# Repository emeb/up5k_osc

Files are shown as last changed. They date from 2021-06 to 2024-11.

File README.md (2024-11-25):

# up5k_osc
An FPGA-based digital oscillator for Eurorack

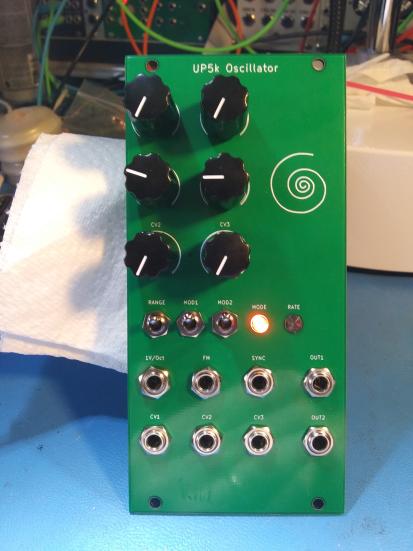
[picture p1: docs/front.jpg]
Front View

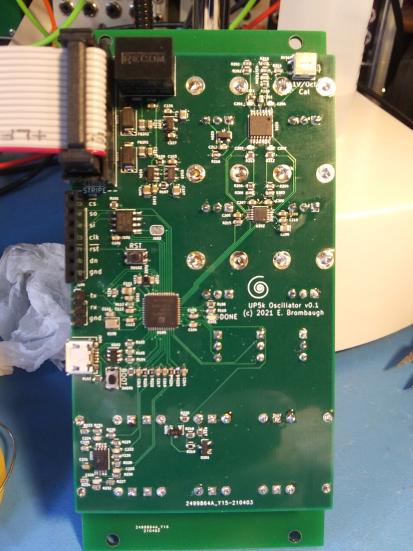
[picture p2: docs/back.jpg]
Back View


## What is it?
up5k_osc is a Eurorack-format digital oscillator demonstrating digital
audio synthesis with a low-cost FPGA. It supports several basic waveforms
commonly found in analog synthesizers, but generated digitally at very high
sample rates to avoid many of the problems with aliasing that occur when
these waveforms are synthesized at lower sample rates.

## Features

* 12HP wide 3U standard Eurorack module
* +/-12V supply on Doepfer-standard 16-pin shrouded, keyed header (30ma max)
* Trimmed 1V/Oct pitch control input with coarse and fine adjustment pots
* Attenuated Exponential FM input
* 3 additional uncommited +/-5V CV inputs with associated setting pots
* Sync input
* Two +/-5V range audio outputs
* Three 3 position toggles for range and mode control
* RGB LED indicator
* Additional single LED indicator
* USB-based firmware updates

## Design details
* Lattice iCE40 Ultra Plus 5k FPGA
* 4MB SPI Flash memory for configuration data, firmware and tables.
* 4-channel 12-bit SPI ADC with 500kSPS max sample rate
* Direct-access SPI Programming header
* 3-pin diagnostic header (2 data + ground)
* Reset and Bootloader pushbuttons
* Done Program LED
* Buck SMPS regulator for low current draw from +12V supply
* Differential PDM DACs for high-resolution, high sample rate and low THD audio

## Resources
* [Schematic](docs/up5k_osc_schematic.pdf)
* [BOM](docs/up5k_osc_bom.ods)

## Motivation
One of the most thorny issues encountered when attempting to synthesize simple
analog waveforms in the digital domain is that of aliasing which occurs due
to sharp transitions coupled with low sample rates. Seemingly "obvious" methods
of generating simple waveforms like sawtooths and square or pulse waves fail
miserably when the sharp edges of these waveforms jitter around due to the low
timing resolution of practical DSP sample rates. Mountains of research have been
devoted to DSP approaches to minimizing this edge jitter using techniques such
as BLIT, BLEP, MinBLEP, PolyBLEP, DPW, etc. These work, but end up becoming
compromises between the complexity of the approach (and the consequent CPU load
they impose) and the degree of alias rejection that they provide.

The brute-force approach is to synthesize these analog waveforms at sufficiently
high sample rates that the timing jitter becomes imperceptible. This is the
method that up5k_osc uses - an audio-rate oscillator is synthesized at sample
rates in excess of 10MHz which knocks the aliases of even the buzziest narrow
pulse wave down below 80dBfs. Differential Pulse Density Modulation is used to
do the digital-to-analog conversion in an inexpensive yet highly linear fashion.

## Theory of Operation
The up5k_osc system comprises a power supply, ADC, Flash Memory, FPGA and analog
I/O processing. 

### Power Supply
Eurorack systems typically provide +/-12V rails at a minimum, and as DSP becomes
a more common feature in typical racks, the +12V rails are disproportionally
loaded down by the use of simple LDO linear regulators to supply the high currents
needed by most modern digital components. up5k_osc uses a SMPS regulator module
to efficiently provide an internal 5V supply from which 3.3V analog and digital
supplys can be derived with less heat and waste.

### Analog Input Processing
A 4-channel 12-bit 500kSPS SPI ADC is used to digitize control voltage inputs
to the up5k_osc. One channel is dedicated to handling the typical 1V/Oct pitch
control and includes trimming to calibrate the 1V/Oct slope, as well as coarse
and fine user offsets as well as summing an attenuated FM input. This provides
roughly 2.7cents/lsb pitch resolution over a 10V range which covers most of
the musical range to an accuracy better than the commonly accepted human
perception.

The other three ADC channels are uncommitted CV inputs with offset controls and
a 10Vpp range. Running that the maximum rated conversion speed, the ADC can
provide 125kSPS per channel which is sufficiently high to provide good temporal
resolution.

### FPGA and SPI Flash
The Lattice iCE40 Ultra Plus 5k FPGA provides a modest gate count, a number of
useful hard IP cores, including SPI, I2C, Multiply-Accumulate and large RAM.
These resources are sufficient for reasonably complex DSP, soft processor cores
and I/O tasks. In the up5k_osc, the FPGA is loaded from the SPI Flash at power
up and immediately begins execution of a basic processing pipeline which begins
with driving a continuous stream of conversions from the ADC, formatting the
results for control of a fast internal NCO, waveshaping and then finally
generating the PDM output signals.

FPGA bitstreams, along with soft processor firmware and synthesis tables are
stored in the SPI flash. During development it's often simplest to directly load
the FPGA over the SPI configuration bus via a programming dongle and header on
the board, bypassing the SPI flash. In end-use situations however it's desirable
to have a simpler approach, and for that purpose a USB interface is provided
which uses the NO2 bootloader and the standardized DFU protocol to load data
into the SPI flash without extra hardware.

[NO2 Bootloader](https://github.com/no2fpga/no2bootloader)

The up5k_osc FPGA pinout for USB, SPI Flash and boot select button + LED has
been designed to follow that of the icebreaker bitsy, so building the
bootloader with that configuration will generate a usable bitstream.

### Switches and LEDs
User control options are provided in the form of three 3-position SPDT toggles
(on-off-on) which can be used to set pitch range, waveform types, etc. A few
LEDs are also provided to indicate operating conditions.

### Analog Outputs
Two PDM DACs are available with fully differential inputs from the FPGA to
improve linearity despite mismatches in rise & fall timing. A two-stage
lowpass reconstruction filter rolls off at about 30kHz, allowing harmonic
content well above normal human hearing range. SNR has been observed as better
that 90dBfs, THD for 1kHz sine is better than 80dBfs and with 16MSPS sample
rates the aliasing on naive sawtooth waveforms are lower than 80dBfs beyond
10kHz. Output levels of 10Vpp are compatible with common Eurorack standards.

## Gateware
Demonstration gateware for the up5k_osc is provided which handles all the basic
functions of an oscillator. Three pitch ranges are provided which cover rates
from 13min/cycle to 10kHz. Two output waveforms can be selected from among
sine/saw/pulse, with pulsewidth controlled by one of the CV inputs.

As delivered the demo gateware does not use a soft processor core. A serial
diagnostic output is generated by simple state machine logic to provide
observation of the ADC conversion results (formatted as 115k 8N1 serial). An
alternate build is possible via macro definitions in the source code that
enables a RISC-V core that can do more complex diagnostics, or even control
the oscillator with some imagination and more coding.

## Future Work
Going beyond this is certainly possible - wavetable morphing has been tested and
other synthesis techniques such as multi-operator FM are possible. The USB
interface could be employed to turn the module into an Audio class peripheral
that handles MIDI or PCM audio.

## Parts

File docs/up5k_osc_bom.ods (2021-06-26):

Reference | Quantity | Value | Footprint | Distributor
C102 C103 C215 C216 C218 C226 | 6 | 1uf | Capacitors_SMD:C_0603 | stock
C101 C104 C105 C108 C109 C110 C112 C113 C114 C210 C211 C212 C220 C221 | 14 | 0.1uf | Capacitors_SMD:C_0603 | stock
C106 C107 C111 C208 C228 | 5 | 10uf | Capacitors_SMD:C_0805 | stock
C201 C202 C203 C204 | 4 | 330pf | Capacitors_SMD:C_0603 | stock
C213 C214 C217 C219 | 4 | 4.7nf | Capacitors_SMD:C_0603 | Digi-Key
C222 C223 C224 C225 | 4 | 75pf | Capacitors_SMD:C_0603 | Digi-Key
C205 C206 C207 C209 C227 | 5 | 0.01uf | Capacitors_SMD:C_0603 | stock
D101 D104 | 2 | LED | LEDs:LED_0603 | stock
D102 | 1 | D | Diodes_SMD:D_0603 | stock
D103 | 1 | ASMB-KTF0-0A306‎ | footprints:ASMB-KTF0-0A306‎ | stock
D201 | 1 | BAT54S | Package_TO_SOT_SMD:SOT-23 | stock
D205 D206 | 2 | D | Diodes_SMD:D_SMA | stock
FB201 FB202 | 2 | 220 | Resistors_SMD:R_0805 | stock
J101 | 1 | USB_OTG | footprints:USB_Micro-B_10103594-0001LF_actual_outline | stock
J102 | 1 | NC Jumper | Jumper:SolderJumper-2_P1.3mm_Bridged_RoundedPad1.0x1.5mm | `---
J103 | 1 | Conn_01x07 | Pin_Headers:Pin_Header_Straight_1x07_Pitch2.54mm | stock
J104 | 1 | Conn_01x03 | Pin_Headers:Pin_Header_Straight_1x03_Pitch2.54mm | stock
J204 | 1 | Conn_02x08_Odd_Even | footprints:5103308-3 | stock
J201 J202 J203 J205 J206 J207 J208 J209 | 8 | AudioJack2_SwitchT | footprints:Jack_3.5mm_QingPu_WQP-PJ398SM_Vertical_CircularHoles | Thonk / stock
Q201 | 1 | MMBT3904 | TO_SOT_Packages_SMD:SOT-23 | stock
R102 | 1 | 1M | Resistors_SMD:R_0603 | Digi-Key
R103 | 1 | 1.5k | Resistors_SMD:R_0603 | stock
R104 R105 | 2 | 22 | Resistors_SMD:R_0603 | stock
R107 R109 R201 R203 R205 R207 R208 | 7 | 100k | Resistors_SMD:R_0603 | stock
R101 R106 R108 R217 R218 R220 | 6 | 10k | Resistors_SMD:R_0603 | stock
R110 | 1 | 2.2k | Resistors_SMD:R_0603 | stock
R111 R112 R215 R233 R234 | 5 | 100 | Resistors_SMD:R_0603 | stock
R202 R204 R206 R209 | 4 | 49.9k | Resistors_SMD:R_0603 | stock
R210 | 1 | 1.2M | Resistors_SMD:R_0603 | Digi-Key
R211 R212 R213 | 3 | 33.2k | Resistors_SMD:R_0603 | stock
R214 | 1 | 32.4k | Resistors_SMD:R_0603 | Digi-Key
R216 | 1 | 2.5k | Resistors_SMD:R_0603 | Digi-Key
R219 | 1 | 60k | Resistors_SMD:R_0603 | stock
R221 R222 R223 R224 | 4 | 1k | Resistors_SMD:R_0603 | stock
R225 R226 R227 R228 | 4 | 47k | Resistors_SMD:R_0603 | stock
R229 R230 R231 R232 | 4 | 71.5k | Resistors_SMD:R_0603 | stock
RV201 RV202 RV203 RV204 RV205 RV206 | 6 | 10k | footprints:Potentiometer_TT_P0915N | stock
RV207 | 1 | 1k | footprints:23BR500LFTR | Digi-Key
SW101 SW102 | 2 | SW_Push | Buttons_Switches_SMD:SW_SPST_KMR2 | stock
SW103 SW104 SW105 | 3 | SW_SPDT | footprints:SPDT_Submini | stock
U101 | 1 | W25Q32JVSS | Housings_SOIC:SOIC-8_3.9x4.9mm_Pitch1.27mm | stock
U102 | 1 | NUP4202 | TO_SOT_Packages_SMD:SOT-23-6 | stock
U103 | 1 | MCP1824x-OT | TO_SOT_Packages_SMD:SOT-23-5 | stock
U104 | 1 | MCP1802x-xx02xOT | TO_SOT_Packages_SMD:SOT-23-5 | stock
U105 | 1 | ice5lp4k_sg48 | footprints:QFN-48-1EP_7x7mm_Pitch0.5mm_DIY_PADS | stock
U106 | 1 | 12MHz | Oscillators:Oscillator_SMD_SeikoEpson_SG210-4pin_2.5x2.0mm | stock
U201 | 1 | MCP6004 | Housings_SSOP:TSSOP-14_4.4x5mm_Pitch0.65mm | stock
U202 | 1 | ADC124S051 | Housings_SSOP:MSOP-10_3x3mm_Pitch0.5mm | stock
U203 | 1 | TL072PW | Housings_SSOP:TSSOP-8_4.4x3mm_Pitch0.65mm | stock
U204 | 1 | LM4040DBZ-5 | Package_TO_SOT_SMD:SOT-23 | stock
U205 | 1 | LP2985-3.3 | Package_TO_SOT_SMD:SOT-23-5 | stock
U210 | 1 | R-78E5.0-0.5 | Converter_DCDC:Converter_DCDC_RECOM_R-78E-0.5_THT | Digi-Key
light pipe | 2 | light pipe | na | Digi-Key

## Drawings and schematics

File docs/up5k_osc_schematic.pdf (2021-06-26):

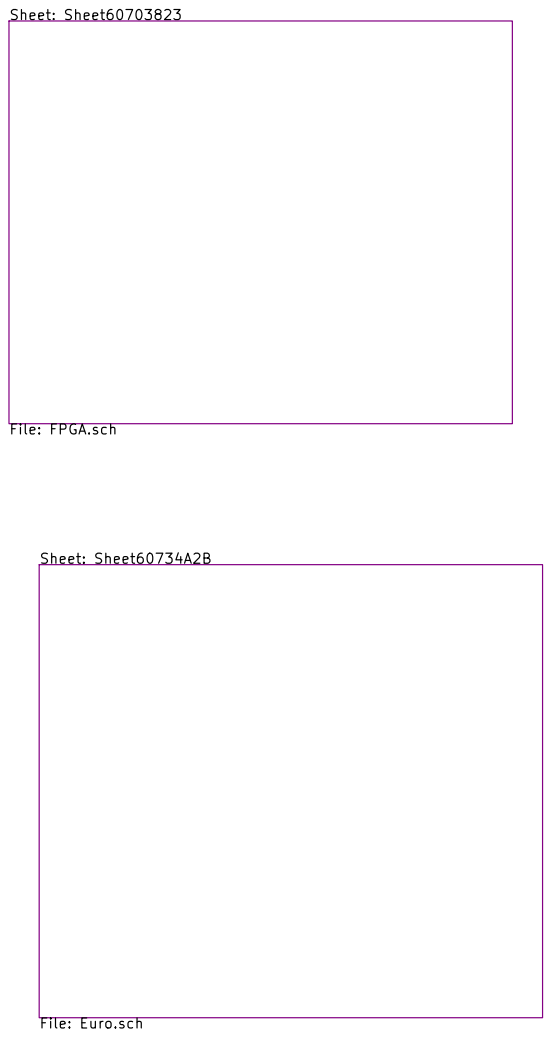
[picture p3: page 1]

Sheet: Sheet60703823 File: FPGA.sch Sheet: Sheet60734A2B

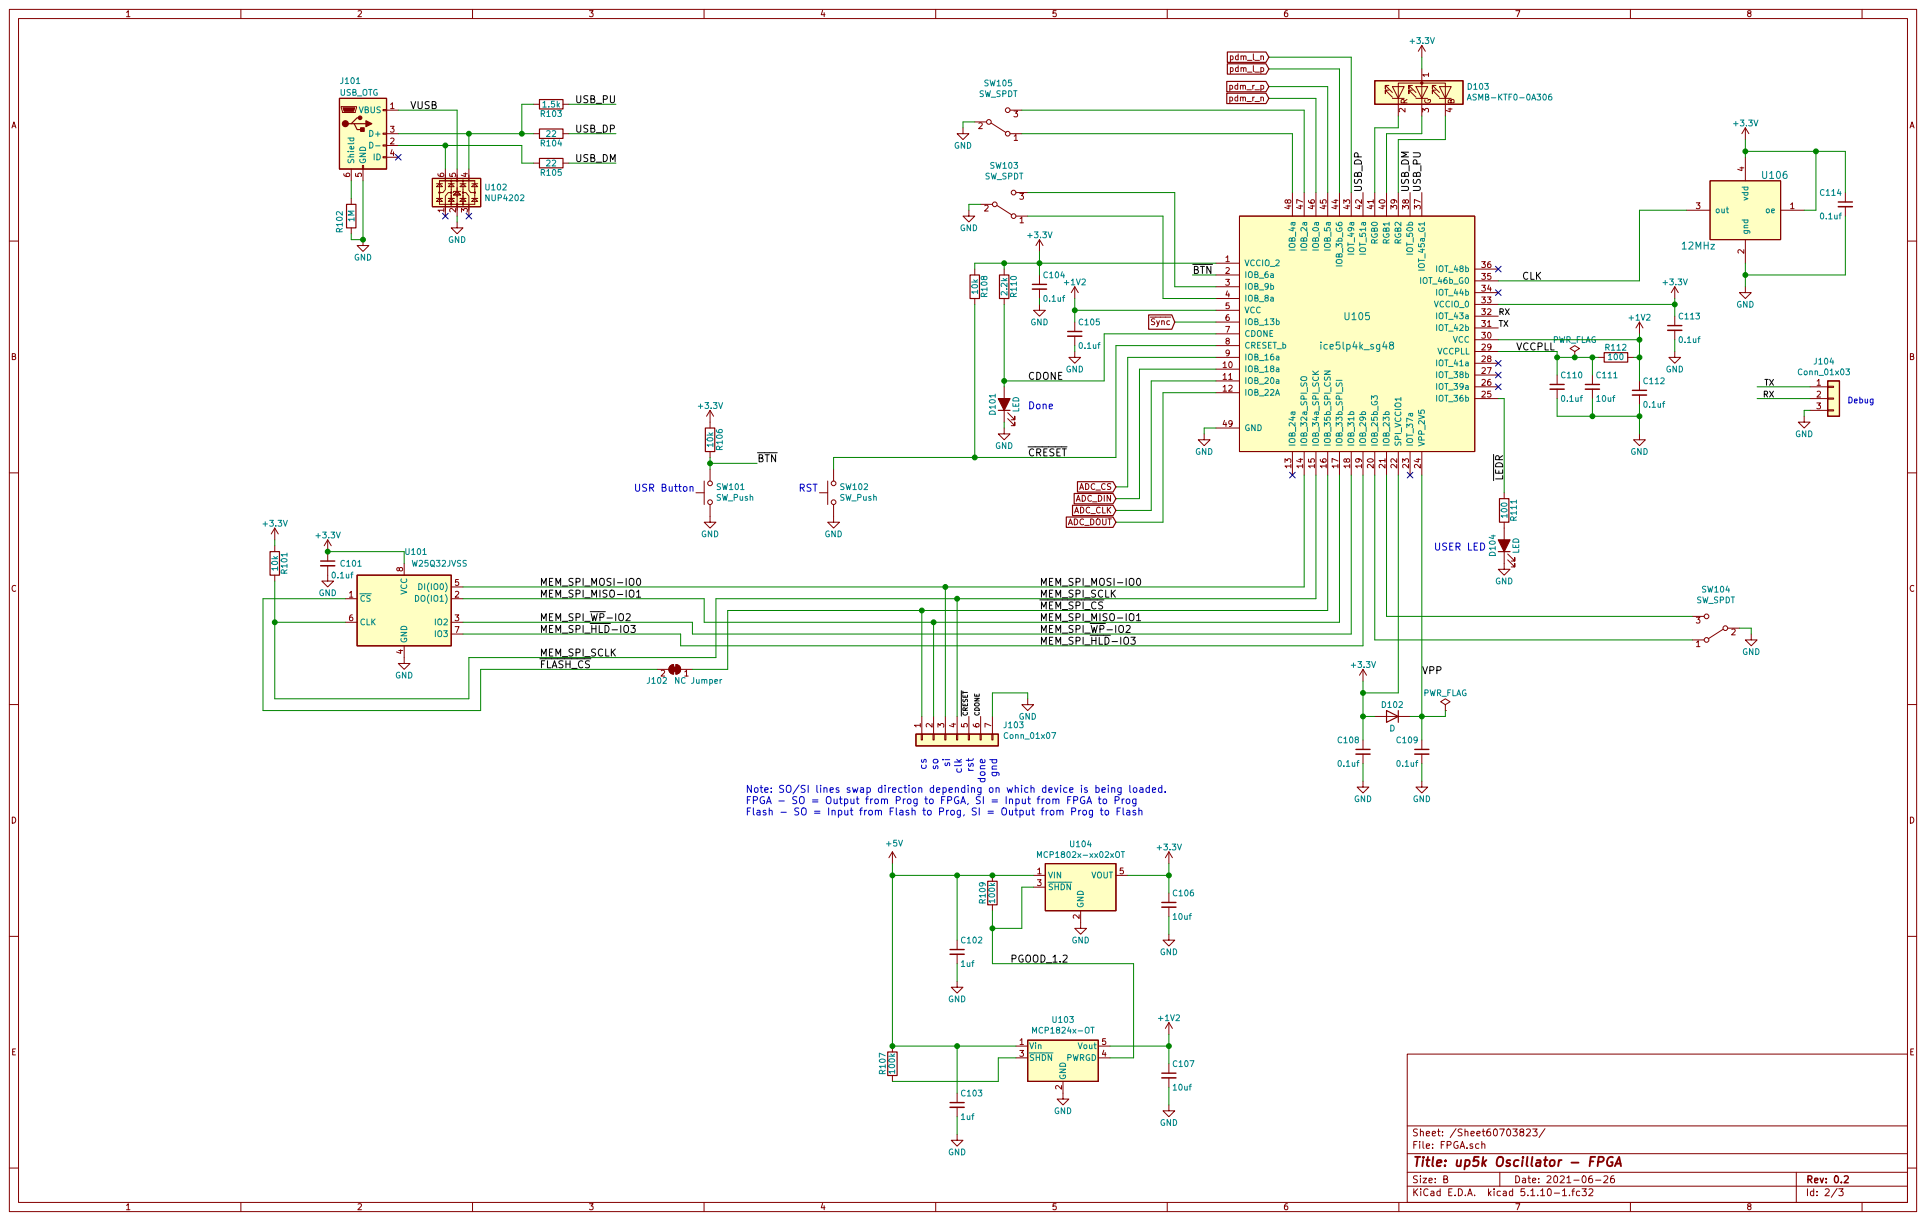
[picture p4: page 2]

MEM_SPI_HLD-IO3

Note: SO/SI lines swap direction depending on which device is being loaded.
FPGA - SO = Output from Prog to FPGA, SI = Input from FPGA to Prog
Flash - SO = Input from Flash to Prog, SI = Output from Prog to Flash

Id: 2/3 Title: up5k Oscillator - FPGA

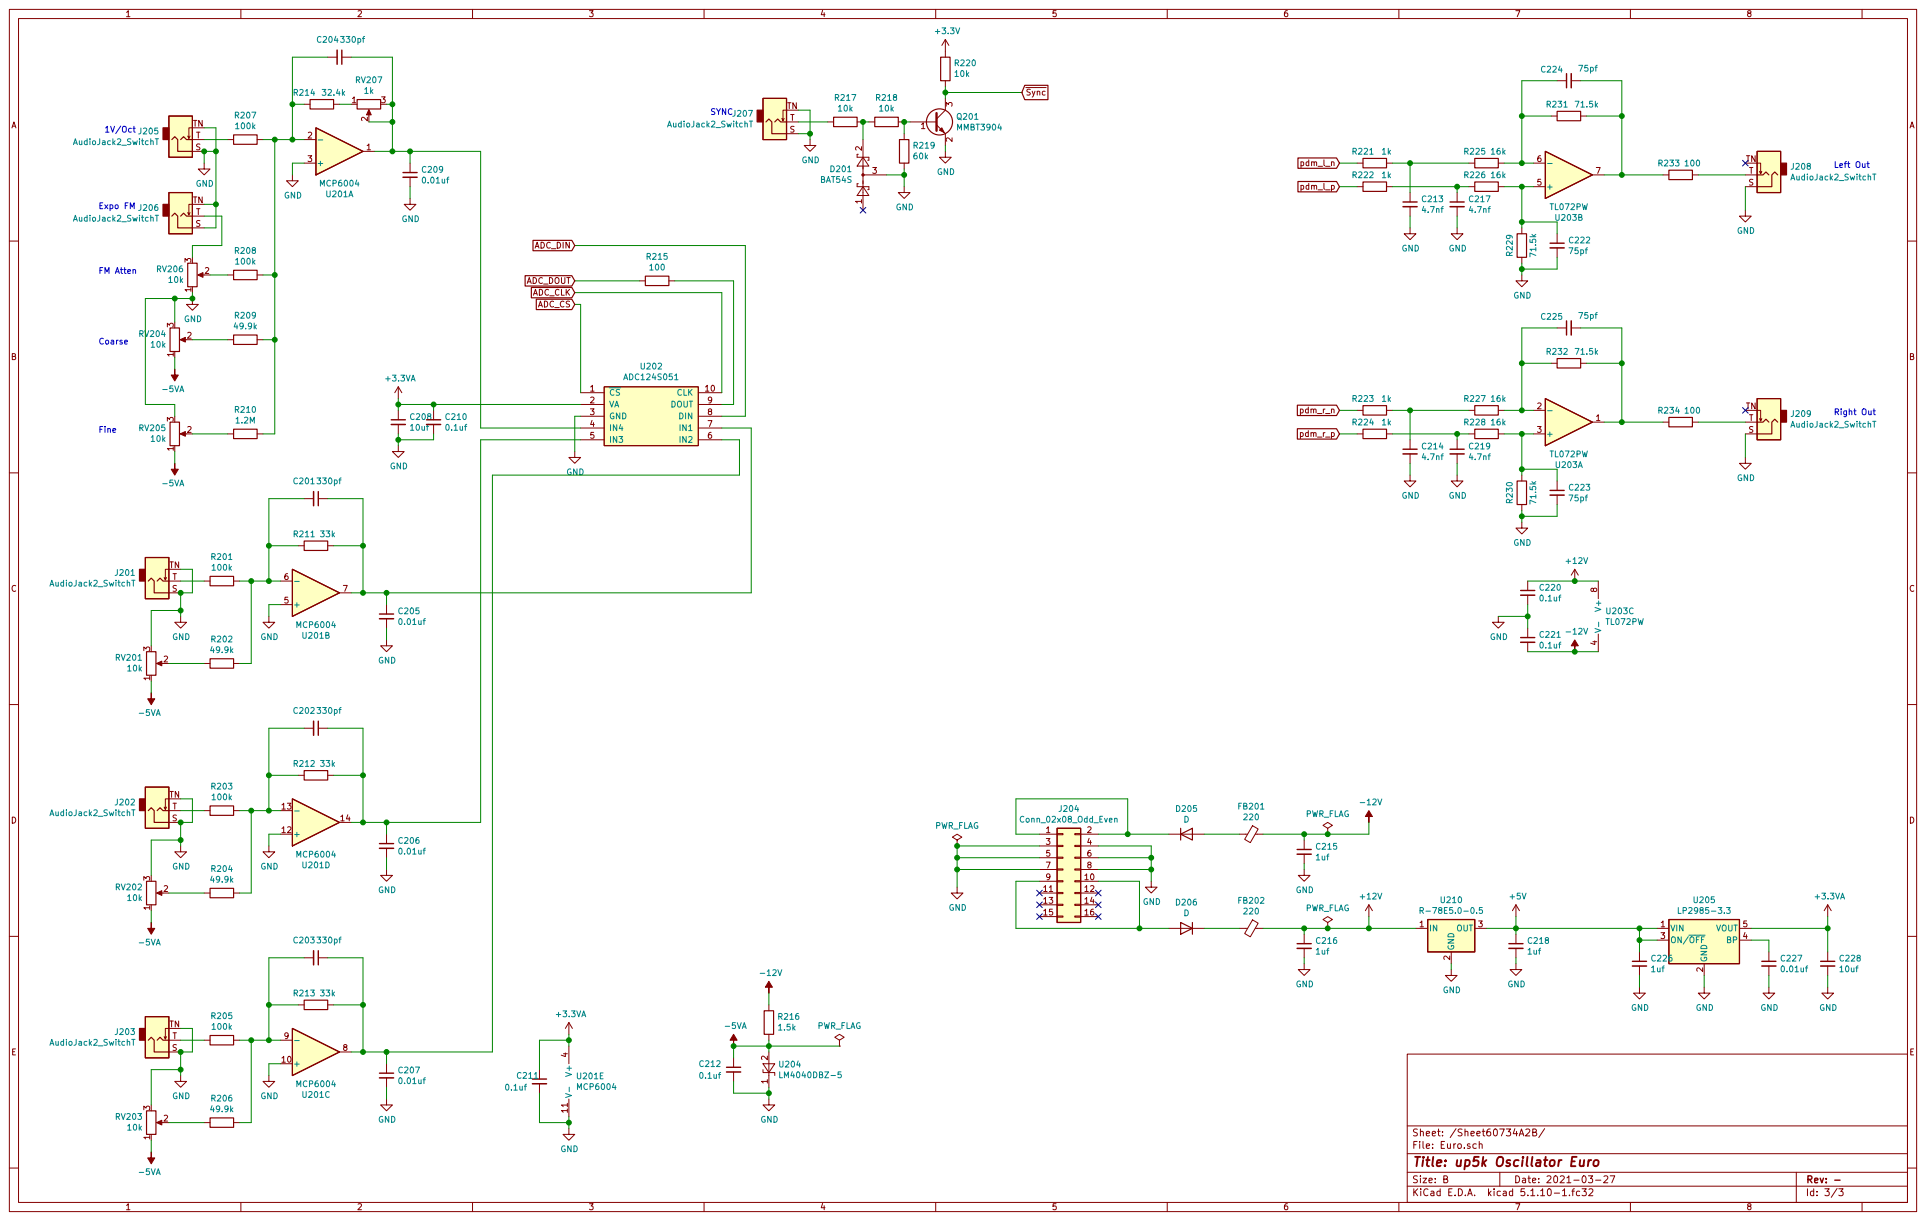
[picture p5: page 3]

Id: 3/3 Title: up5k Oscillator Euro File: Euro.sch Sheet: /Sheet60734A2B/ R203

9 | 10

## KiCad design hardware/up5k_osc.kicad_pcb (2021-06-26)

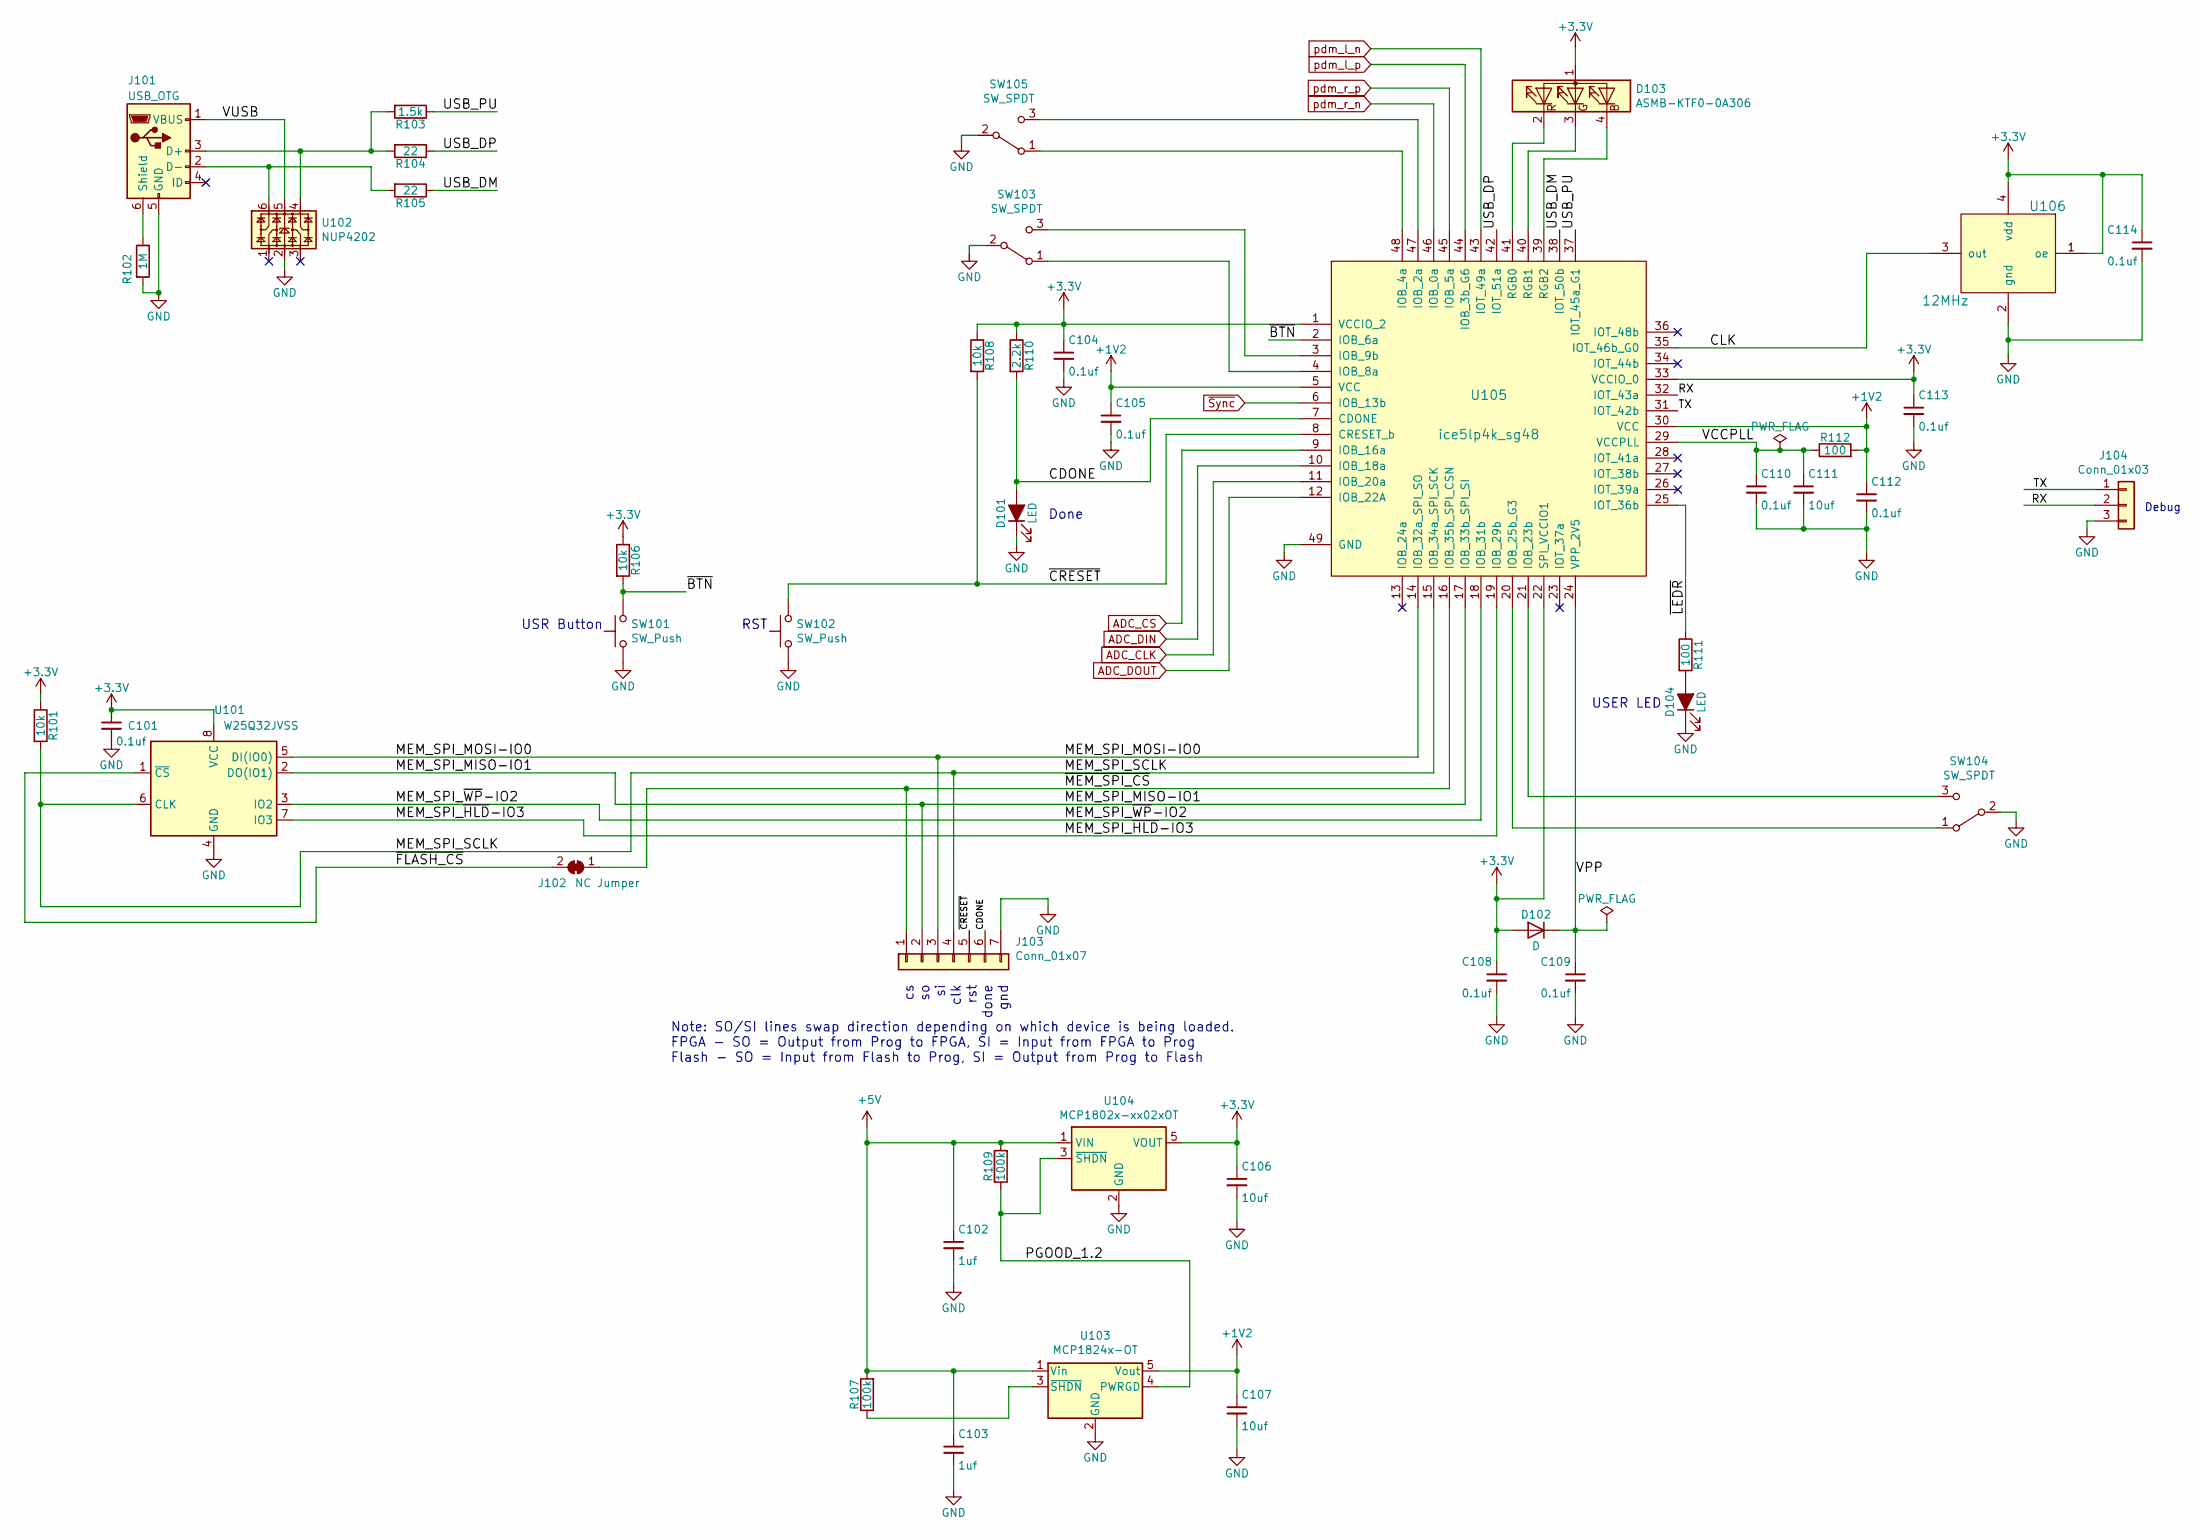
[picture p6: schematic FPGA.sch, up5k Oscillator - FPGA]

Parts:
C101, C104, C105, C108, C109, C110, C112, C113, C114: 0.1uf; C_0603
C102, C103: 1uf; C_0603
C106, C107, C111: 10uf; C_0805
D101, D104: LED; LED_0603
D102: D; D_0603
D103: ASMB-KTF0-0A306‎
J101: USB_OTG; USB_Micro-B_10103594-0001LF_actual_outline
J102: NC Jumper; SolderJumper-2_P1.3mm_Bridged_RoundedPad1.0x1.5mm
J103: Conn_01x07; Pin_Header_Straight_1x07_Pitch2.54mm
J104: Conn_01x03; Pin_Header_Straight_1x03_Pitch2.54mm
R101, R106, R108: 10k; R_0603
R102: 1M; R_0603
R103: 1.5k; R_0603
R104, R105: 22; R_0603
R107, R109: 100k; R_0603
R110: 2.2k; R_0603
R111, R112: 100; R_0603
SW101, SW102: SW_Push; SW_SPST_KMR2
SW103, SW104, SW105: SW_SPDT; SPDT_Submini
U101: W25Q32JVSS; SOIC-8_3.9x4.9mm_Pitch1.27mm
U102: NUP4202; SOT-23-6
U103: MCP1824x-OT; SOT-23-5
U104: MCP1802x-xx02xOT; SOT-23-5
U105: ice5lp4k_sg48; QFN-48-1EP_7x7mm_Pitch0.5mm_DIY_PADS
U106: 12MHz; Oscillator_SMD_SeikoEpson_SG210-4pin_2.5x2.0mm

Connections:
+1V2: C105.1, C107.1, C112.1, R112.2, U103.5 (Vout), U105.5 (VCC), U105.30 (VCC)
+3V3: C101.1, C104.1, C106.1, C108.1, C113.1, C114.1, D102.2 (A), D103.1 (A), R101.1, R106.1, R108.1, R110.1, U101.8 (VCC), U104.5 (VOUT), U105.1 (VCCIO_2), U105.22 (SPI_VCCIO1), U105.33 (VCCIO_0), U106.1 (oe), U106.4 (vdd); also elsewhere on the board
+5V: C102.1, C103.1, R107.2, R109.2, U103.1 (Vin), U104.1 (VIN); also elsewhere on the board
/Sheet60703823/CDONE: D101.2 (A), J103.6, R110.2, U105.7 (CDONE)
/Sheet60703823/CLK: U105.35 (IOT_46b_G0), U106.3 (out)
/Sheet60703823/MEM_SPI_MISO-IO1: J103.2, U101.2 (DO(IO1)), U105.17 (IOB_33b_SPI_SI)
/Sheet60703823/MEM_SPI_MOSI-IO0: J103.3, U101.5 (DI(IO0)), U105.14 (IOB_32a_SPI_SO)
/Sheet60703823/MEM_SPI_SCLK: J103.4, R101.2, U101.6 (CLK), U105.15 (IOB_34a_SPI_SCK)
/Sheet60703823/MEM_SPI_~HLD~-IO3: U101.7 (IO3), U105.19 (IOB_29b)
/Sheet60703823/MEM_SPI_~WP~-IO2: U101.3 (IO2), U105.18 (IOB_31b)
/Sheet60703823/PGOOD_1.2: R109.1, U103.4 (PWRGD), U104.3 (~SHDN)
/Sheet60703823/RX: J104.2, U105.32 (IOT_43a)
/Sheet60703823/TX: J104.1, U105.31 (IOT_42b)
/Sheet60703823/USB_DM: R105.1, U105.38 (IOT_50b)
/Sheet60703823/USB_DP: R104.1, U105.42 (IOT_51a)
/Sheet60703823/USB_PU: R103.1, U105.37 (IOT_45a_G1)
/Sheet60703823/VCCPLL: C110.1, C111.1, R112.1, U105.29 (VCCPLL)
/Sheet60703823/VPP: C109.1, D102.1 (K), U105.24 (VPP_2V5)
/Sheet60703823/VUSB: J101.1 (VBUS), U102.5
/Sheet60703823/~BTN: R106.2, SW101.2, U105.2 (IOB_6a)
/Sheet60703823/~CRESET: J103.5, R108.2, SW102.2, U105.8 (CRESET_b)
/Sheet60703823/~FLASH_CS: J102.2 (B), U101.1 (~CS)
/Sheet60703823/~LEDR: R111.1, U105.25 (IOT_36b)
/Sheet60703823/~MEM_SPI_CS: J102.1 (A), J103.1, U105.16 (IOB_35b_SPI_CSN)
ADC_CLK: U105.11 (IOB_20a); also elsewhere on the board
ADC_CS: U105.9 (IOB_16a); also elsewhere on the board
ADC_DIN: U105.10 (IOB_18a); also elsewhere on the board
ADC_DOUT: U105.12 (IOB_22A); also elsewhere on the board
GND: C101.2, C102.2, C103.2, C104.2, C105.2, C106.2, C107.2, C108.2, C109.2, C110.2, C111.2, C112.2, C113.2, C114.2, D101.1 (K), D104.1 (K), J101.5 (GND), J103.7, J104.3, R102.2, SW101.1, SW102.1, SW103.2 (B), SW104.2 (B), SW105.2 (B), U101.4 (GND), U102.2, U103.2 (GND), U104.2 (GND), U105.49 (GND), U106.2 (gnd); also elsewhere on the board
unnamed: D103.2 (RK), U105.41 (RGB0)
unnamed: D103.3 (GK), U105.40 (RGB1)
unnamed: D103.4 (BK), U105.39 (RGB2)
unnamed: D104.2 (A), R111.2
unnamed: J101.2 (D-), R105.2, U102.6
unnamed: J101.3 (D+), R103.2, R104.2, U102.4
unnamed: J101.6 (Shield), R102.1
unnamed: R107.1, U103.3 (~SHDN)
unnamed: SW103.1 (A), U105.4 (IOB_8a)
unnamed: SW103.3 (C), U105.3 (IOB_9b)
unnamed: SW104.1 (A), U105.20 (IOB_25b_G3)
unnamed: SW104.3 (C), U105.21 (IOB_23b)
unnamed: SW105.1 (A), U105.48 (IOB_4a)
unnamed: SW105.3 (C), U105.47 (IOB_2a)
pdm_l_n: U105.43 (IOT_49a); also elsewhere on the board
pdm_l_p: U105.44 (IOB_3b_G6); also elsewhere on the board
pdm_r_n: U105.46 (IOB_0a); also elsewhere on the board
pdm_r_p: U105.45 (IOB_5a); also elsewhere on the board
~Sync: U105.6 (IOB_13b); also elsewhere on the board

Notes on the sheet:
clk
rst
done
gnd
Done
Note: SO/SI lines swap direction depending on which device is being loaded. FPGA - SO = Output from Prog to FPGA, SI = Input from FPGA to Prog Flash - SO = Input from Flash to Prog, SI = Output from Prog to Flash
RST
USR Button
USER LED
Debug

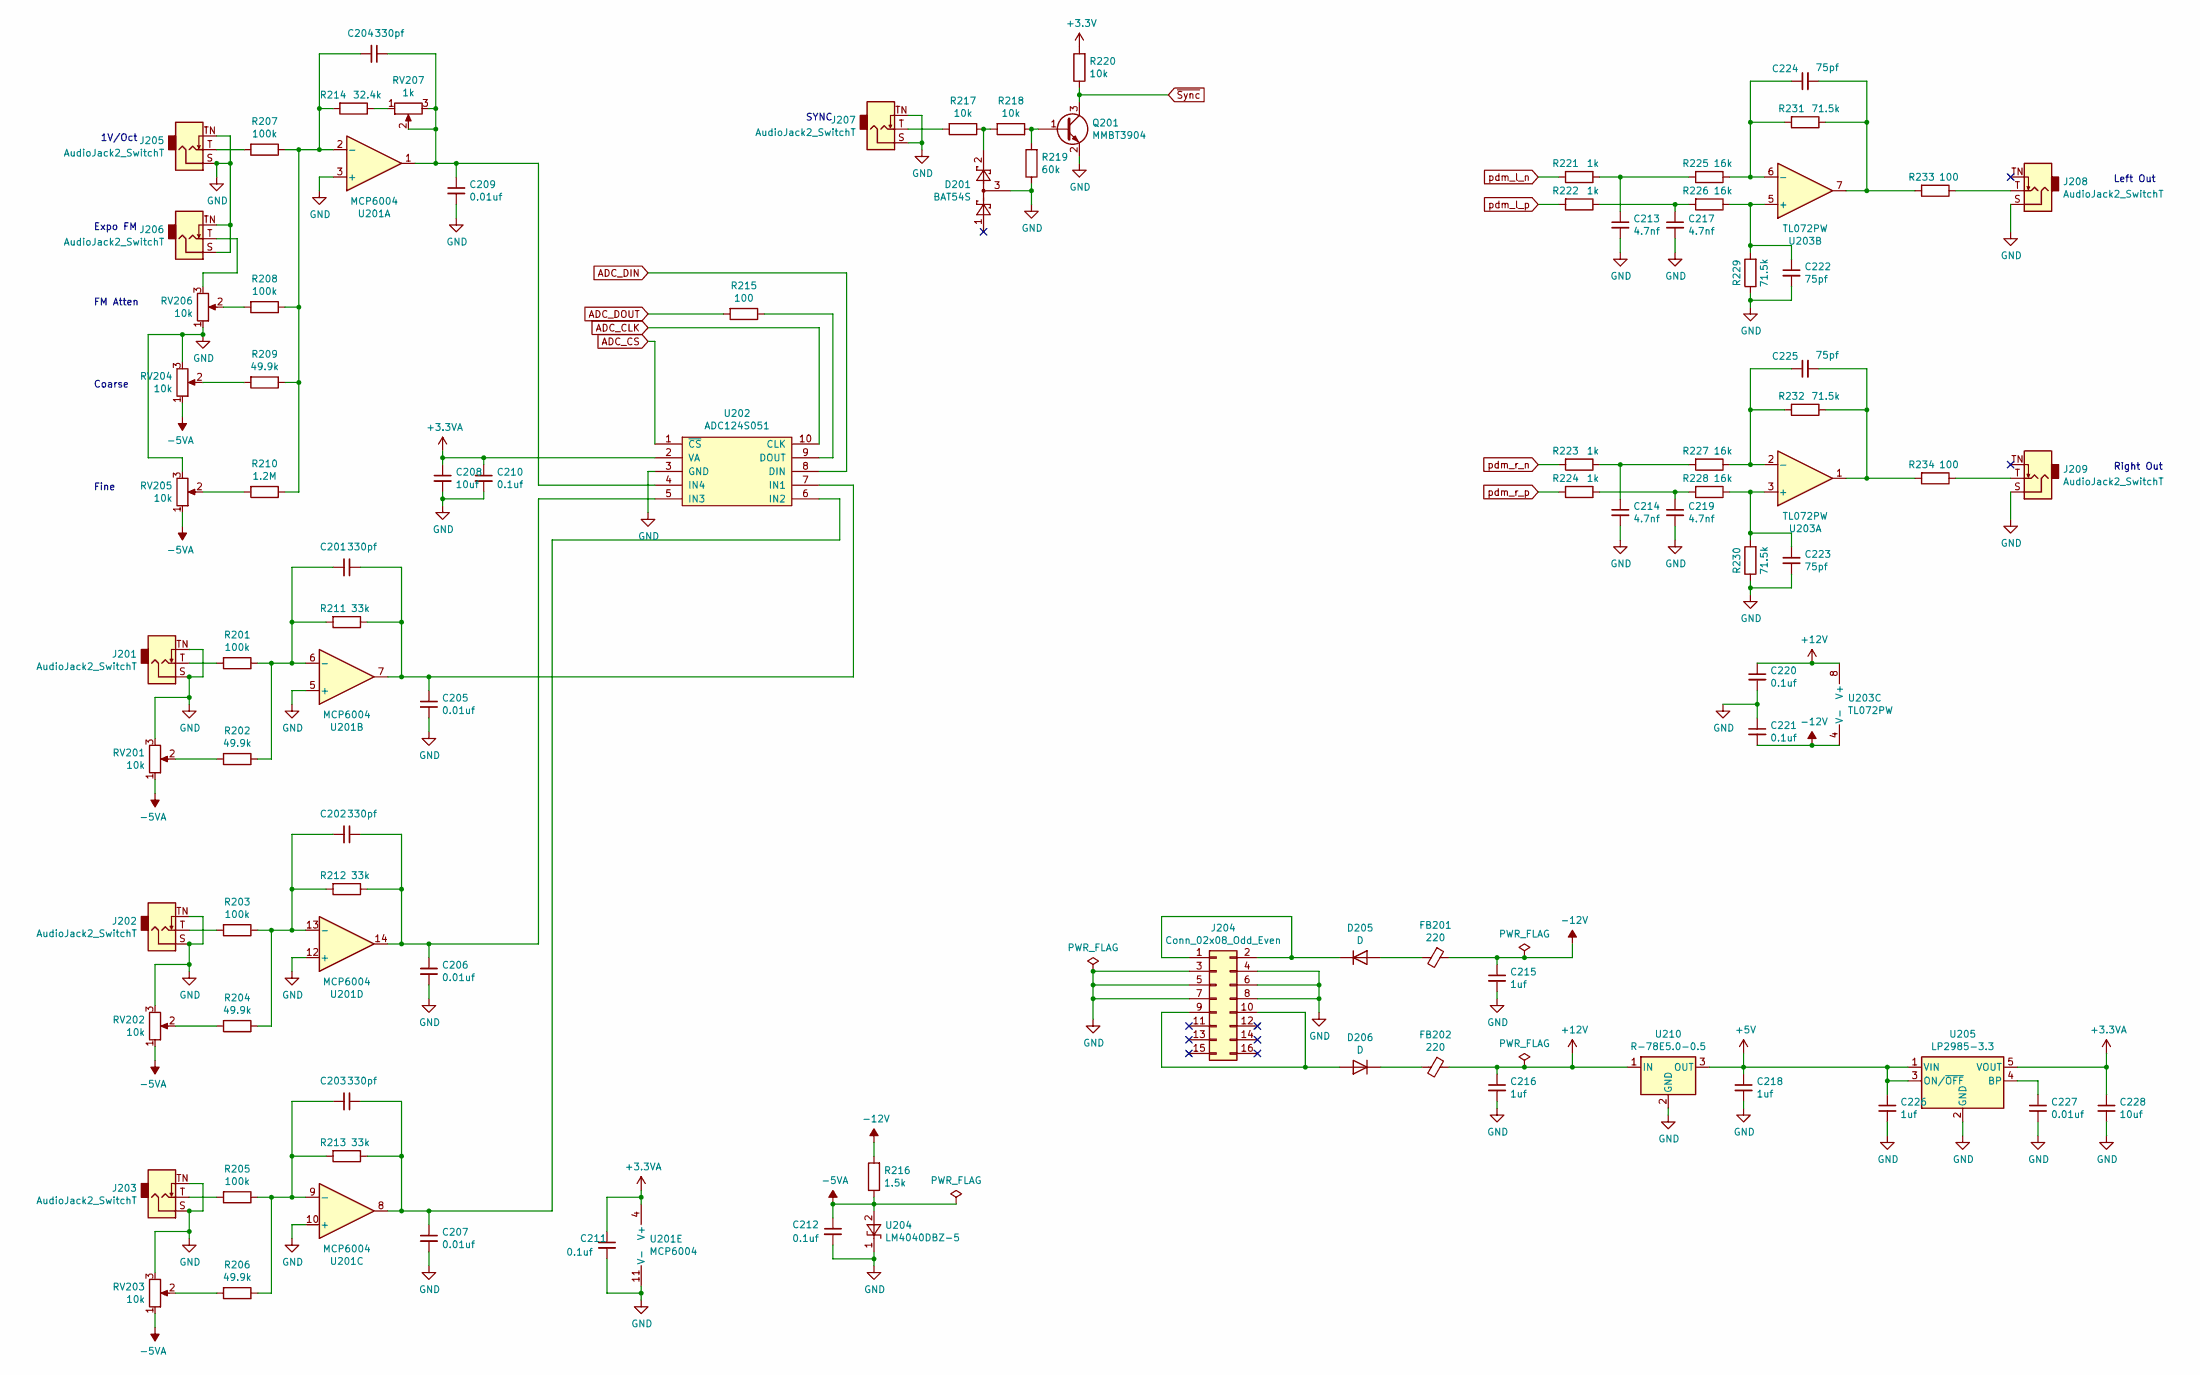
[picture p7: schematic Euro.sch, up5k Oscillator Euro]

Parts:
C201, C202, C203, C204: 330pf; C_0603
C205, C206, C207, C209, C227: 0.01uf; C_0603
C208, C228: 10uf; C_0805
C210, C211, C212, C220, C221: 0.1uf; C_0603
C213, C214, C217, C219: 4.7nf; C_0603
C215, C216, C218, C226: 1uf; C_0603
C222, C223, C224, C225: 75pf; C_0603
D201: BAT54S; SOT-23
D205, D206: D; D_SMA
FB201, FB202: 220; R_0805
J201, J202, J203, J205, J206, J207, J208, J209: AudioJack2_SwitchT; Jack_3.5mm_QingPu_WQP-PJ398SM_Vertical_CircularHoles
J204: Conn_02x08_Odd_Even; 5103308-3
Q201: MMBT3904; SOT-23
R201, R203, R205, R207, R208: 100k; R_0603
R202, R204, R206, R209: 49.9k; R_0603
R210: 1.2M; R_0603
R211, R212, R213: 33k; R_0603
R214: 32.4k; R_0603
R215, R233, R234: 100; R_0603
R216: 1.5k; R_0603
R217, R218, R220: 10k; R_0603
R219: 60k; R_0603
R221, R222, R223, R224: 1k; R_0603
R225, R226, R227, R228: 16k; R_0603
R229, R230, R231, R232: 71.5k; R_0603
RV201, RV202, RV203, RV204, RV205, RV206: 10k; Potentiometer_TT_P0915N
RV207: 1k; 23BR500LFTR
U201: MCP6004; TSSOP-14_4.4x5mm_Pitch0.65mm
U202: ADC124S051; MSOP-10_3x3mm_Pitch0.5mm
U203: TL072PW; TSSOP-8_4.4x3mm_Pitch0.65mm
U204: LM4040DBZ-5; SOT-23
U205: LP2985-3.3; SOT-23-5
U210: R-78E5.0-0.5; Converter_DCDC_RECOM_R-78E-0.5_THT

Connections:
+3.3VA: C208.1, C210.1, C211.1, C228.1, U201.4 (V+), U202.2 (VA), U205.5 (VOUT)
+3V3: R220.2; also elsewhere on the board
+5V: C218.1, C226.1, U205.1 (VIN), U205.3 (ON/~OFF~), U210.3 (OUT); also elsewhere on the board
+12V: C216.1, C220.1, FB202.1, U203.8 (V+), U210.1 (IN)
-5VA: C212.1, R216.1, RV201.1, RV202.1, RV203.1, RV204.1, RV205.1, U204.2 (A)
-12V: C215.1, C221.2, FB201.1, R216.2, U203.4 (V-)
ADC_CLK: U202.10 (CLK); also elsewhere on the board
ADC_CS: U202.1 (~CS); also elsewhere on the board
ADC_DIN: U202.8 (DIN); also elsewhere on the board
ADC_DOUT: R215.2; also elsewhere on the board
GND: C205.2, C206.2, C207.2, C208.2, C209.2, C210.2, C211.2, C212.2, C213.2, C214.2, C215.2, C216.2, C217.2, C218.2, C219.2, C220.2, C221.1, C222.2, C223.2, C226.2, C227.2, C228.2, D201.3, J201.S, J201.TN, J202.S, J202.TN, J203.S, J203.TN, J204.3, J204.4, J204.5, J204.6, J204.7, J204.8, J205.S, J205.TN, J206.S, J206.TN, J207.S, J207.TN, J208.S, J209.S, Q201.2 (E), R219.1, R229.1, R230.1, RV201.3, RV202.3, RV203.3, RV204.3, RV205.3, RV206.1, U201.3 (+), U201.5 (+), U201.10 (+), U201.11 (V-), U201.12 (+), U202.3 (GND), U204.1 (K), U205.2 (GND), U210.2 (GND); also elsewhere on the board
unnamed: C201.1, C205.1, R211.1, U201.7, U202.7 (IN1)
unnamed: C201.2, R201.1, R202.1, R211.2, U201.6 (-)
unnamed: C202.1, C206.1, R212.1, U201.14, U202.5 (IN3)
unnamed: C202.2, R203.1, R204.1, R212.2, U201.13 (-)
unnamed: C203.1, C207.1, R213.1, U201.8, U202.6 (IN2)
unnamed: C203.2, R205.1, R206.1, R213.2, U201.9 (-)
unnamed: C204.1, C209.1, RV207.2, RV207.3, U201.1, U202.4 (IN4)
unnamed: C204.2, R207.1, R208.1, R209.1, R210.1, R214.2, U201.2 (-)
unnamed: C213.1, R221.1, R225.2
unnamed: C214.1, R223.1, R227.2
unnamed: C217.1, R222.1, R226.2
unnamed: C219.1, R224.1, R228.2
unnamed: C222.1, R226.1, R229.2, U203.5 (+)
unnamed: C223.1, R228.1, R230.2, U203.3 (+)
unnamed: C224.1, R225.1, R231.2, U203.6 (-)
unnamed: C224.2, R231.1, R233.2, U203.7
unnamed: C225.1, R227.1, R232.2, U203.2 (-)
unnamed: C225.2, R232.1, R234.2, U203.1
unnamed: C227.1, U205.4 (BP)
unnamed: D201.2, R217.1, R218.2
unnamed: D205.1 (K), J204.1, J204.2
unnamed: D205.2 (A), FB201.2
unnamed: D206.1 (K), FB202.2
unnamed: D206.2 (A), J204.9, J204.10
unnamed: J201.T, R201.2
unnamed: J202.T, R203.2
unnamed: J203.T, R205.2
unnamed: J205.T, R207.2
unnamed: J206.T, RV206.3
unnamed: J207.T, R217.2
unnamed: J208.T, R233.1
unnamed: J209.T, R234.1
unnamed: Q201.1 (B), R218.1, R219.2
unnamed: R202.2, RV201.2
unnamed: R204.2, RV202.2
unnamed: R206.2, RV203.2
unnamed: R208.2, RV206.2
unnamed: R209.2, RV204.2
unnamed: R210.2, RV205.2
unnamed: R214.1, RV207.1
unnamed: R215.1, U202.9 (DOUT)
pdm_l_n: R221.2; also elsewhere on the board
pdm_l_p: R222.2; also elsewhere on the board
pdm_r_n: R223.2; also elsewhere on the board
pdm_r_p: R224.2; also elsewhere on the board
~Sync: Q201.3 (C), R220.1; also elsewhere on the board

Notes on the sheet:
1V/Oct
Expo FM
Coarse
Fine
FM Atten
Left Out
Right Out
SYNC

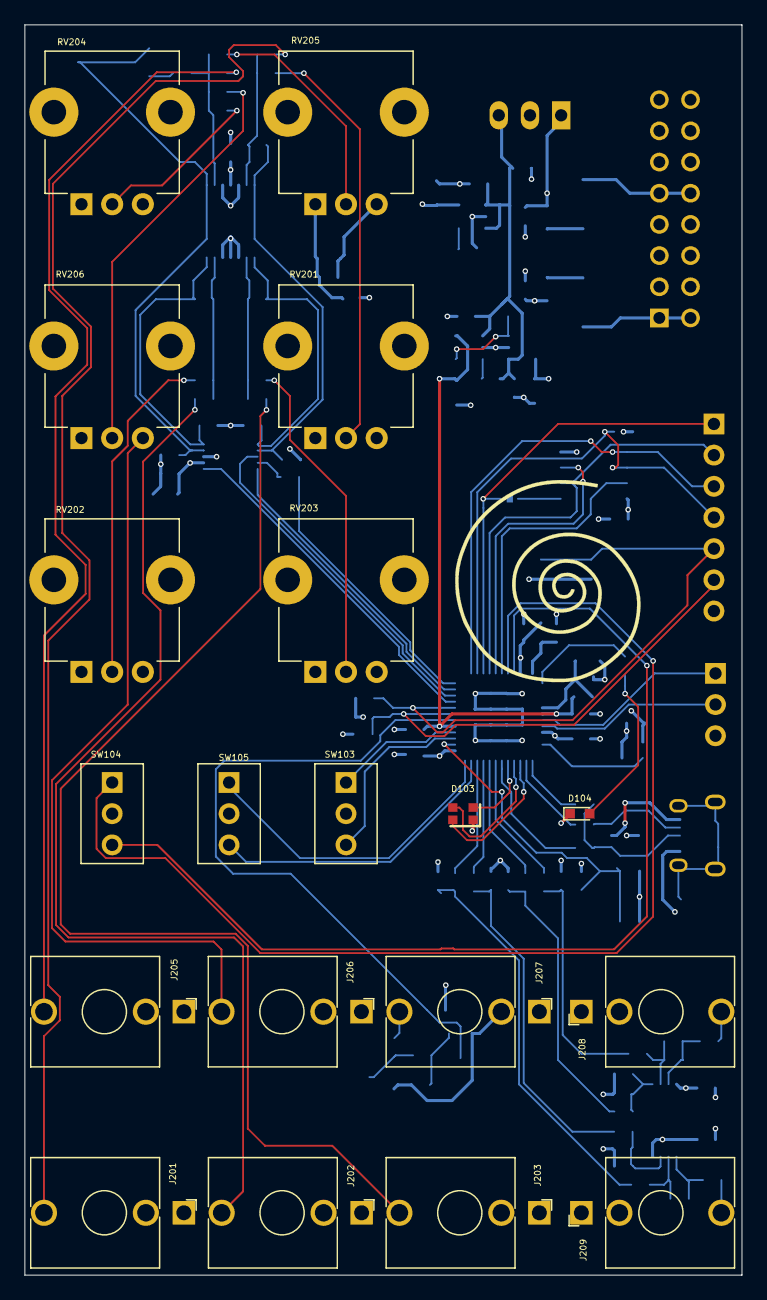
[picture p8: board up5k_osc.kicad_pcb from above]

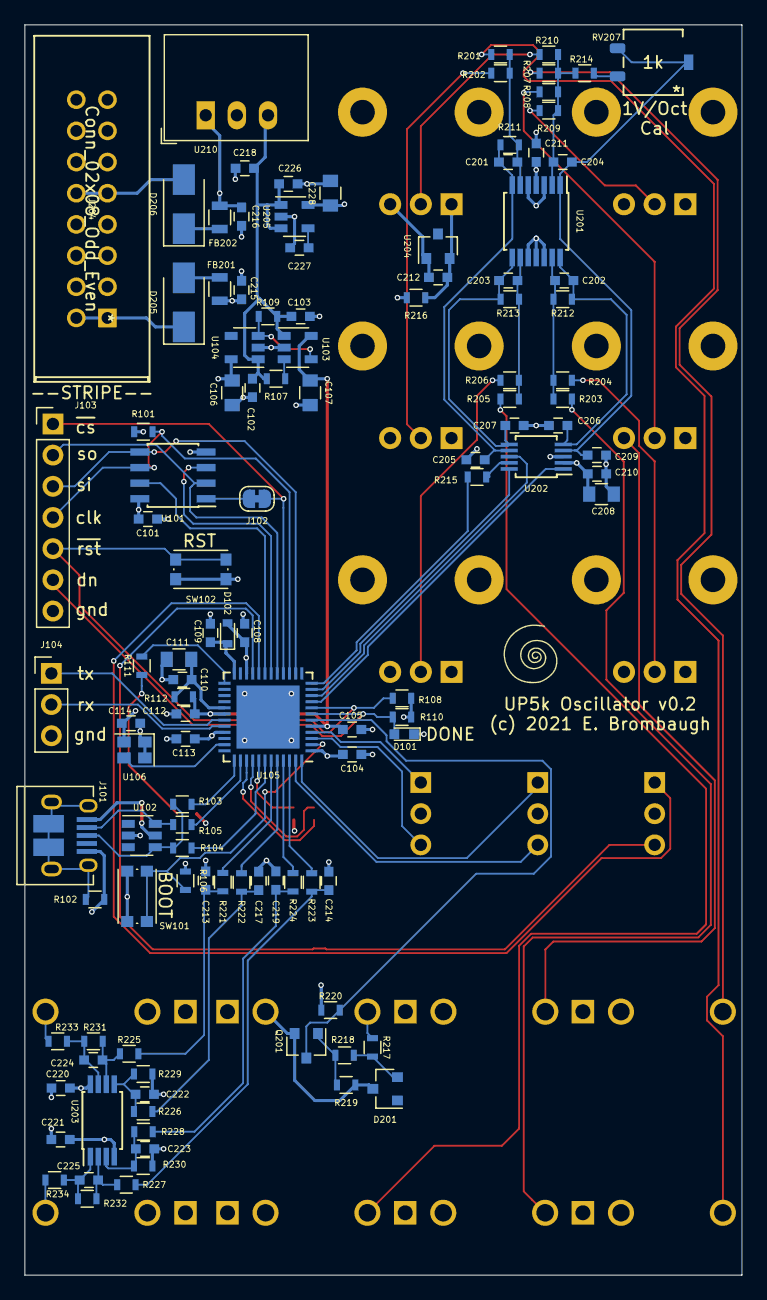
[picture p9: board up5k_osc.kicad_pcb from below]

Board: 4 copper layers, 58.4 x 101.9 mm, 137 parts (117 on the bottom side), 93 nets.

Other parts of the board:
Ref**: Val**; avatar_small
Ref**#2: Val**; avatar

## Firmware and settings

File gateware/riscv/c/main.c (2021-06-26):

/*
 * main.c - top level of picorv32 firmware
 * 06-30-19 E. Brombaugh
 */

#include <stdio.h>
#include "up5k_osc.h"
#include "acia.h"
#include "printf.h"
#include "clkcnt.h"

/*
 * main... duh
 */
void main()
{
	uint32_t cnt;
	
	init_printf(0,acia_printf_putc);
	printf("\n\n\rup5k_osc - Diagnostics\n\r");
	
	cnt = 0;
	while(1)
	{
		/* ADC inputs */
		printf("%03X ", gp_in0 & 0xFFF);
		printf("%03X ", gp_in1 & 0xFFF);
		printf("%03X ", gp_in2 & 0xFFF);
		printf("%03X ", gp_in3 & 0xFFF);
		
		/* switch & sync inputs */
		printf("%01X ", (gp_in0>>12) & 0x3);
		printf("%01X ", (gp_in1>>12) & 0x3);
		printf("%01X ", (gp_in2>>12) & 0x3);
		printf("%01X ", (gp_in3>>12) & 0x3);
		
		gp_out = (gp_out&~(0xF<<17))|((cnt&0xF)<<17);
		printf("cnt = %d\n\r", cnt);
		cnt++;
		clkcnt_delayms(1000);
	}
}

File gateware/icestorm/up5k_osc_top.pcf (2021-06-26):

# Pin assignments for up5k_osc project

set_io clk_12 35

set_io adc_si  10
set_io adc_so  12
set_io adc_clk 11
set_io adc_cs  9

set_io pdm_l_p 44
set_io pdm_l_n 43
set_io pdm_r_p 45
set_io pdm_r_n 46

set_io RGB0 39
set_io RGB1 40
set_io RGB2 41

set_io LEDR 25

set_io rx 32
set_io tx 31

set_io SYNC 6

#set_io BTN 2

set_io -pullup yes SW103[0] 3
set_io -pullup yes SW103[1] 4

set_io -pullup yes SW104[0] 21
set_io -pullup yes SW104[1] 20

set_io -pullup yes SW105[0] 47
set_io -pullup yes SW105[1] 48

#set_io MEM_SPI_MOSI_IO0 14
#set_io MEM_SPI_SCLK 15
#set_io MEM_SPI_CS 16
#set_io MEM_SPI_MISO_IO1 17
#set_io MEM_SPI_WP_IO2 18
#set_io MEM_SPI_HLD_IO3 19

#set_io usb_dp 42
#set_io usb_dn 38
#set_io usb_pu 37

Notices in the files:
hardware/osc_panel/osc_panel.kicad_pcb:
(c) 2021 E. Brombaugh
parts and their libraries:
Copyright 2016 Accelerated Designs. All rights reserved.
